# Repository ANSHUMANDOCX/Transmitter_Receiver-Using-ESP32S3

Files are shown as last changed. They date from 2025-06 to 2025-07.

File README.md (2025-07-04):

# Transmitter_Receiver-Using-ESP32S3
This is an RF ESP32-S3-based 10-channel Transmitter and Receiver which can also be used with the ESP-NOW protocol.

## PARTS
- ESP32-S3 WROOM-1U
- NRF24L01+ Transceiver Module
- SSD1309 2.42 inch OLED
- 2 Joysticks
- 4 Switches
- 2 Potentiometers

## PLAN
This is an RF transmitter with 10 channels, all of which support PWM output. The 10 channels include: 4 from joysticks 2 from potentiometers 4 from toggle switches

The setup includes a 2.42-inch OLED display to show the status of each channel, bind status, and battery level.

The receiver and transmitter will be programmed using an FTDI module.

The transmitter is designed to run for 5–6 hours on a 1000mAh LiPo battery (ideally).

The code is subject to change depending on in hand testing currently its just a sample code for controlling 10 servo motor with the 10 inputs.
# Transmitter 




# Receiver




## BOM

| Supplier | Item | Price (USD) |
|---|---|---|
| **LCSC** | Joystick (x2) | $0.85 |
| | SSD1309 2.42" OLED | $11.28 |
| | ESP32-S3 WROOM | $7.69 |
| | Potentiometer (x2) | $3.31 |
| | Switches (x4) | $2.33 |
| | MIC5219 3.3V LDO | $1.41 |
| | Pin headers+passive component | $7.71 |
| | Shipping | $3.74 |
| | **Total (LCSC)** | **$38.05**  |
| **JLCPCB** | PCB | $6.00 |
| | Shipping | $14.00 |
| | **Total (JLCPCB)** | **$20.00**  |
| **Sharvi Electronics** | nRF24L01+ + Heatset Insert + Charging Module+antenna | $9.53|
| | **Total (Sharvi)** | **$9.53** |
| **Electronics Comp.** | Battery | $5.38 |
| | **Total (Electronics Comp.)** | **$5.38** |

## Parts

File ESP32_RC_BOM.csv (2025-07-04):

Component | Price (USD) | Quantity | Total (USD) | BUY LINKS/LCSC PartNo.
ESP32-S3-WROOM-1U-N8 | 3.84 | 2 | 7.68 | C2980297
nRF24L01+ PA/LNA module | 2 | 2 | 4 | https://sharvielectronics.com/product/nrf24l01-sma-wireless-transceiver/
MIC5219-3.3YM5 Regulator | 0.28 | 5 | 1.4 | C5370977
Joysticks (XY axes) | 0.41 | 2 | 0.82 | C37323739,C37323741
Potentiometers | 1.65 | 2 | 3.3 | C2687317
Toggle Switches | 0.58 | 4 | 2.32 | C1788492
OLED Display (SSD1309) | 11.74 | 1 | 11.74 | C7466000
LiPo Battery (2000mAh) | 5.9 | 1 | 5.9 | https://www.electronicscomp.com/3.7v-2000mah-lipo-battery-india
passive components(resistor pinheaders etc) | 7 | 1 | 7 | C2881685,C2935876,C513768,C412252,C7419947,C2935874,C41366842,C2881435,C46635842,C3013349
Heat set inserts and antenna connector For case | 3.847 | 1 | 3.847 | https://sharvielectronics.com/product/pigtail-antenna-cable-rg1-13-ipex-3-0-female-to-ipex-3-0-female-connector-15cm-length/, https://sharvielectronics.com/product/rpsma-male-connector-to-ufl-ipex-interface-cable-15cm/, https://sharvielectronics.com/product/m2x3-mm-brass-heat-set-threaded-round-insert-nut/ https://sharvielectronics.com/product/ufl-male-to-sma-female-pcb-breakout-board/
PCB | 4 | 1 | 4
shipping |  |  | 18
 |  |  | 70.007

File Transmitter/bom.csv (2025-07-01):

Designator | Footprint | Quantity | Value | LCSC Part #
C1, C2, C6, C7, C9 | 805 | 5 | 0.1uF
C10, C11, C12, C13, C3, C4, C5 | 805 | 7 | 22uf
C8 | 1206 | 1 | 0.1uF
D1, D2 | 805 | 2 | Transmission Good
D3, D4 | 805 | 2 | LED
R1, R2 | 805 | 2 | 330R
R3, R4, R6, R7 | 805 | 4 | 10k
R5 | 805 | 1 | 2K
R8 | 1206 | 1 | 2K
SW1, SW3, SW2, SW4 | SW_Push_SPST_NO_Alps_SKRK | 2 | RESET
U1 | ESP32-WROOM-32E | 2 | ESP32-WROOM-32UE
U2, U4 | SOT-223-3_TabPin2 | 2 | AMS1117-3.3
U5 | SOT-223-3_TabPin2 | 1 | AMS1117-5.0

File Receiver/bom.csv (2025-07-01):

Designator | Footprint | Quantity | Value | LCSC Part #
C1 | 0603 | 1 | 1uF
C10, C11, C12, C13, C2, C3, C4, C6, C7, C8, C9 | 0603 | 11 | 0.1uF
C5 | 0603 | 1 | 22uF
D1, D2 | 0603 | 2 | LED
J1, J2, J3 | PinHeader_1x10_P2.54mm_Vertical | 3 | Conn_01x10_Pin
J10 | PinHeader_1x02_P1.27mm_Vertical | 1 | BAT
J11 | PinHeader_1x06_P1.27mm_Vertical | 1 | Conn_01x06_Pin
R1, R2, R7 | 0603 | 3 | 10K
SW2, SW3 | SW_Push_SPST_NO_Alps_SKRK | 2 | SW_Push
U1 | XCVR_ESP32-S3-WROOM-1U | 1 | ESP32-S3-WROOM-1U
U2, U4 | SOT-23-5 | 2 | MIC5219-3.3YM5
U3 | nRF24L01_Breakout | 1 | NRF24L01_Breakout

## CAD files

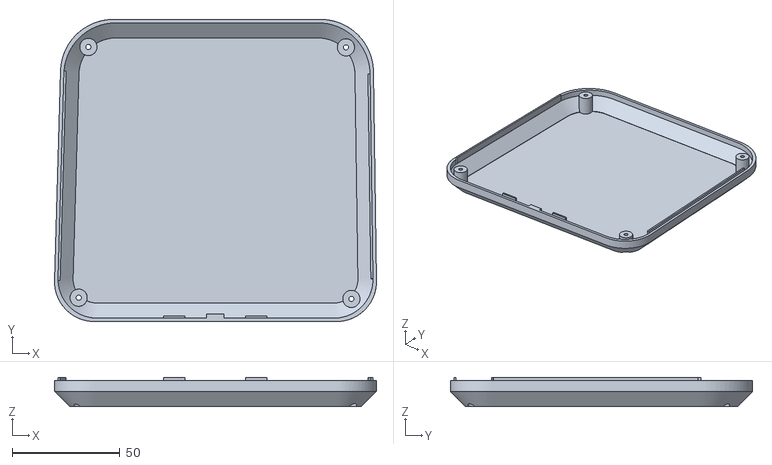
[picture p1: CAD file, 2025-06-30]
CAD/Bottom plate v2.stl
149.2 x 140.0 x 13.5

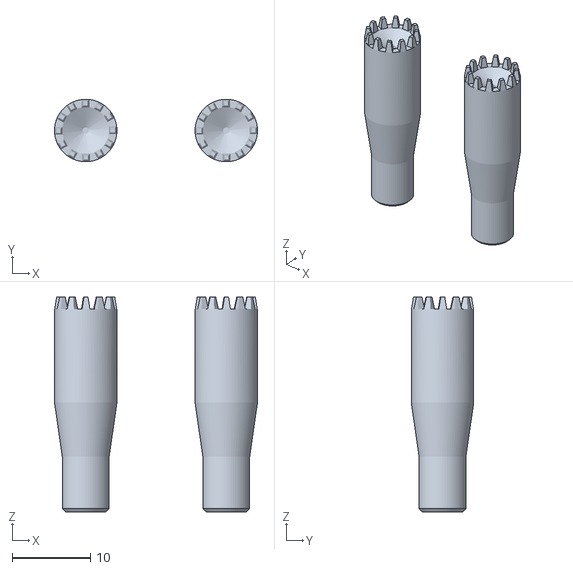
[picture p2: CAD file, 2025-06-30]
CAD/Sticks v3.stl
26.0 x 8.00 x 27.5

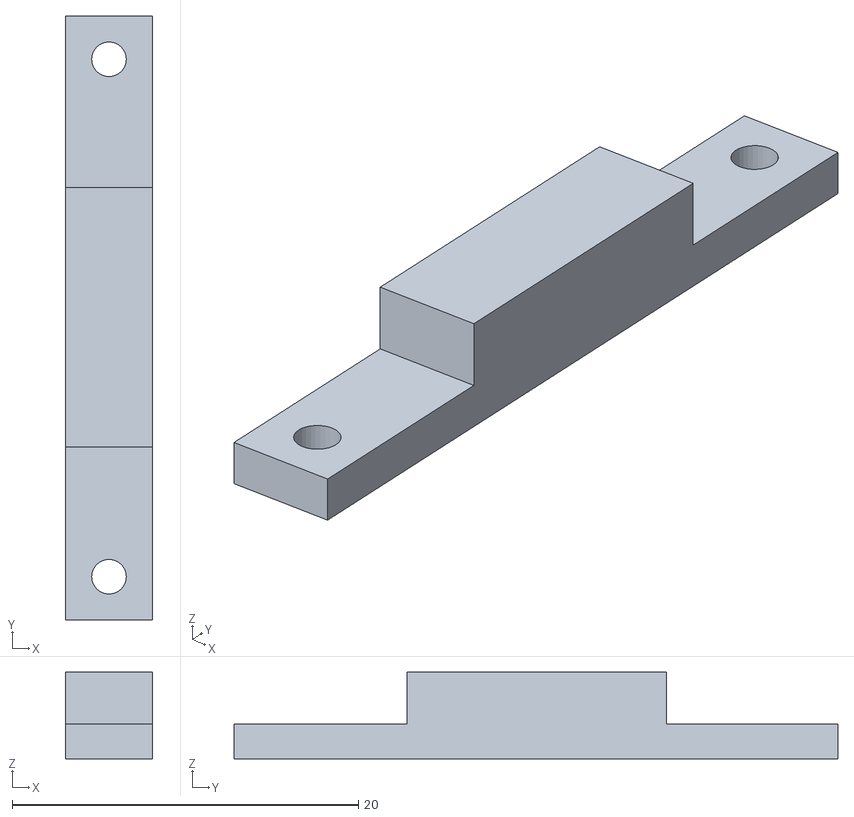
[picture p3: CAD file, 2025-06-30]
CAD/Joystick Placer v1.stl
5.00 x 34.9 x 5.00

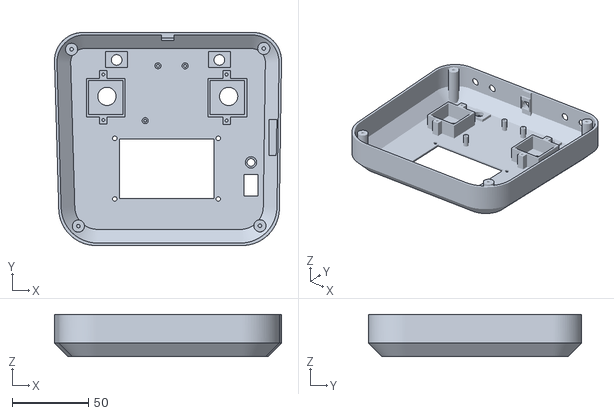
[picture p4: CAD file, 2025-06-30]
CAD/FRONT.stl
149.2 x 140.0 x 27.9

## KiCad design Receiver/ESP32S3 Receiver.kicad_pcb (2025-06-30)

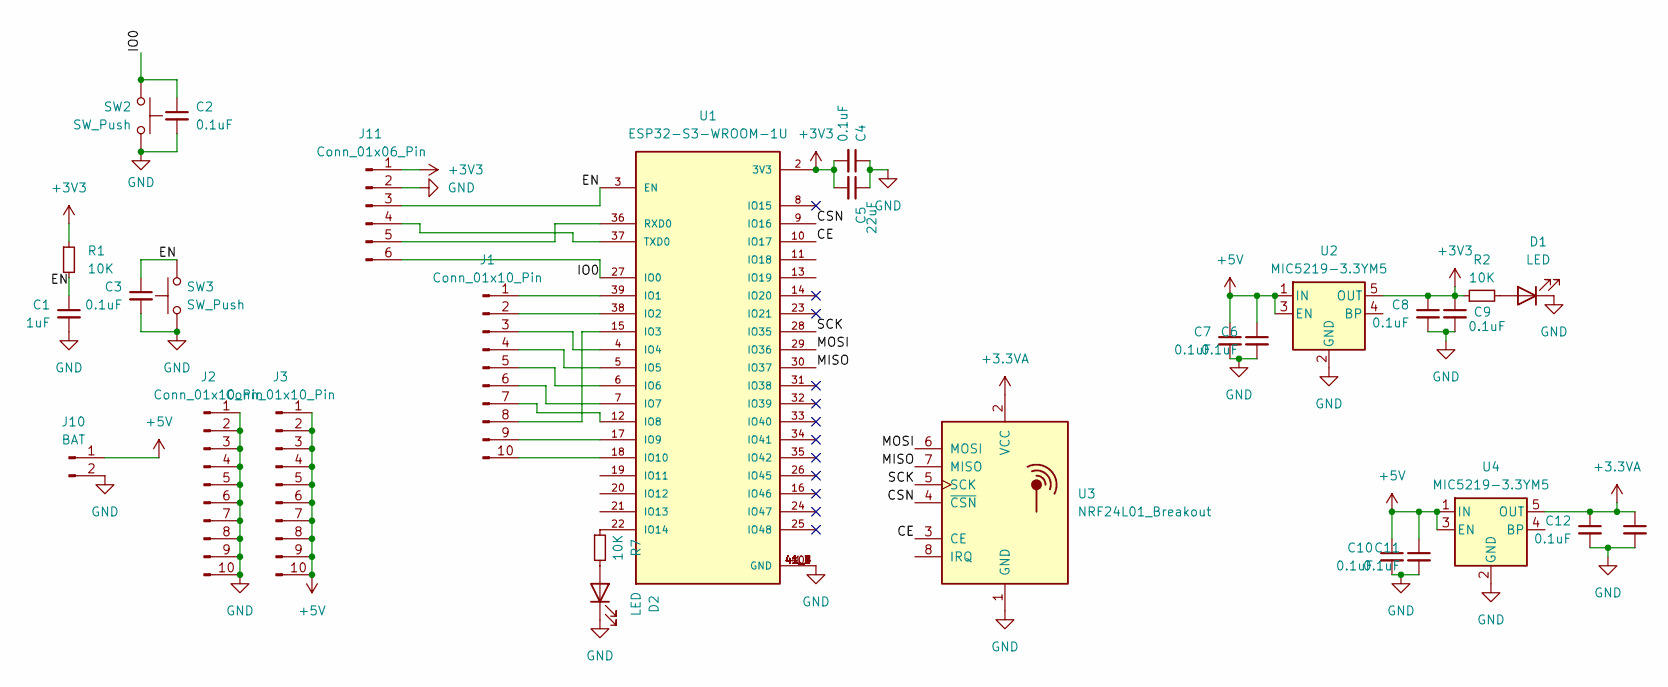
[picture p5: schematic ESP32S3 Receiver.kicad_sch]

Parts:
C1: 1uF; C_0603_1608Metric
C2, C3, C4, C6, C7, C8, C9, C10, C11, C12, C13: 0.1uF; C_0603_1608Metric
C5: 22uF; C_0603_1608Metric
D1, D2: LED; LED_0603_1608Metric_Pad1.05x0.95mm_HandSolder
J1, J2, J3: Conn_01x10_Pin; PinHeader_1x10_P2.54mm_Vertical
J10: BAT; PinHeader_1x02_P1.27mm_Vertical
J11: Conn_01x06_Pin; PinHeader_1x06_P1.27mm_Vertical
R1, R2, R7: 10K; R_0603_1608Metric
SW2, SW3: SW_Push; SW_Push_SPST_NO_Alps_SKRK
U1: ESP32-S3-WROOM-1U; XCVR_ESP32-S3-WROOM-1U; PARTREV v0.6
U2, U4: MIC5219-3.3YM5; SOT-23-5
U3: NRF24L01_Breakout; nRF24L01_Breakout

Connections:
+3.3VA: C12.1, C13.1, U3.2 (VCC), U4.5 (OUT)
+3V3: C4.2, C5.2, C8.1, C9.1, J11.1, R1.1, R2.1, U1.2 (3V3), U2.5 (OUT)
+5V: C6.1, C7.1, C10.1, C11.1, J3.1, J3.2, J3.3, J3.4, J3.5, J3.6, J3.7, J3.8, J3.9, J3.10, J10.1, U2.1 (IN), U2.3 (EN), U4.1 (IN), U4.3 (EN)
/CE: U1.10 (IO17), U3.3 (CE)
/CSN: U1.9 (IO16), U3.4 (~CSN)
/EN: C1.1, C3.1, J11.3, R1.2, SW3.2, U1.3 (EN)
/IO0: C2.1, J11.6, SW2.2, U1.27 (IO0)
/MISO: U1.30 (IO37), U3.7 (MISO)
/MOSI: U1.29 (IO36), U3.6 (MOSI)
/SCK: U1.28 (IO35), U3.5 (SCK)
GND: C1.2, C2.2, C3.2, C4.1, C5.1, C6.2, C7.2, C8.2, C9.2, C10.2, C11.2, C12.2, C13.2, D1.1 (K), D2.1 (K), J2.1, J2.2, J2.3, J2.4, J2.5, J2.6, J2.7, J2.8, J2.9, J2.10, J10.2, J11.2, SW2.1, SW3.1, U1.1 (GND), U1.40 (GND), U1.41_1 (GND), U1.41_2 (GND), U1.41_3 (GND), U1.41_4 (GND), U1.41_5 (GND), U1.41_6 (GND), U1.41_7 (GND), U1.41_8 (GND), U1.41_9 (GND), U2.2 (GND), U3.1 (GND), U4.2 (GND)
unnamed: D1.2 (A), R2.2
unnamed: D2.2 (A), R7.2
unnamed: J1.1, U1.39 (IO1)
unnamed: J1.2, U1.38 (IO2)
unnamed: J1.3, U1.4 (IO4)
unnamed: J1.4, U1.5 (IO5)
unnamed: J1.5, U1.6 (IO6)
unnamed: J1.6, U1.7 (IO7)
unnamed: J1.7, U1.12 (IO8)
unnamed: J1.8, U1.15 (IO3)
unnamed: J1.9, U1.17 (IO9)
unnamed: J1.10, U1.18 (IO10)
unnamed: J11.4, U1.37 (TXD0)
unnamed: J11.5, U1.36 (RXD0)
unnamed: R7.1, U1.22 (IO14)

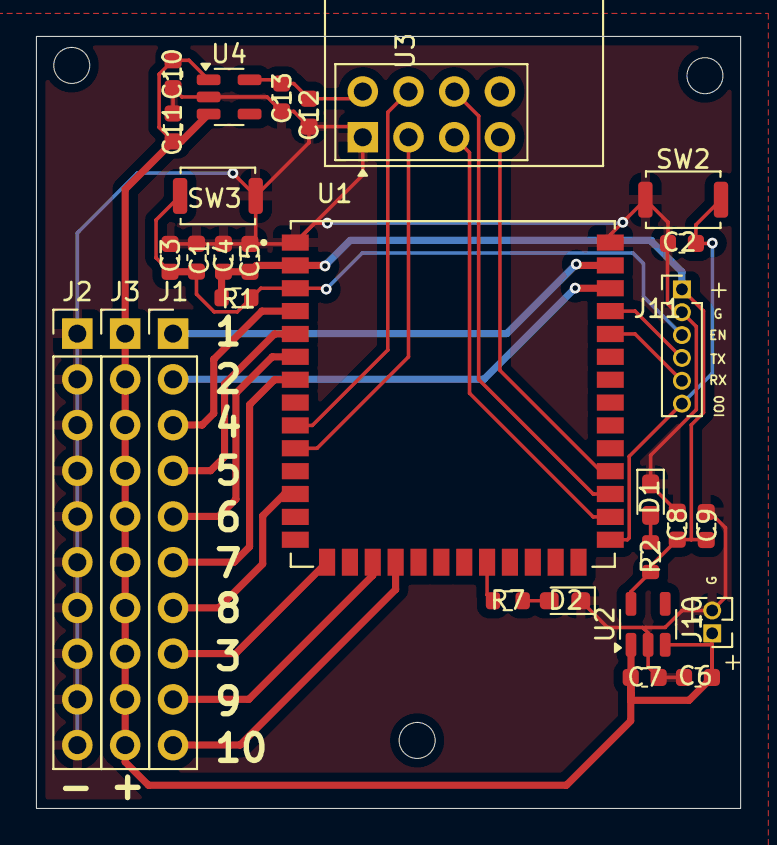
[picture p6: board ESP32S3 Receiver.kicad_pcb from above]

Board: 2 copper layers, 39.1 x 42.9 mm, 29 parts (0 on the bottom side), 26 nets.

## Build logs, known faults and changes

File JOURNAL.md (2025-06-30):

# ESP32S3 Transmitter and Receiver
- **Title:** ESP32S3 Transmitter and Receiver
- **Author:** Anshuman Tripathy
- **Description:** Transmitter and Receiver with 10 channel and a OLED Display.
- **Created_at:** 2025-06-10
- Total Time spent- 22hr

## **DAY 1- 17th June 2025: Started out with the Project**

Reasearched and planned out on what features the transmitter will have searched for the componets read the Datasheets. Since its my first time using esp32 s3 so i had to read the datasheet and look at example circuits properly. So, finally will be using these
- ESP32 S3 Wroom 1u
- SSD1309 2.42 inch oled
- 2 joysticks 2 potentiometes and 4 switched.
- nrf24l01 for rf communication.

Also, started out with the scheamtic 



time spent- 5 hr

## **Day 2 - 22nd June 2025: PCB**

Assigned, arranged th components on the PCB and also complted the routing. Its still a wip would need to complete a few things before finally completing it.



time spent- 4hr 

## **Day 3 - 24th June 2025 : PCB AND CAD**

Completed the PCB and started and complted a major chunk of the front portion of the transmitter where all the joysticks switches and Joysticks will be connected to.
The majority of the time was spent making the CAD. However its still not completed since i still need to make a place to hold the PCB in place.





Time Spent 6hr

## **Day 4 - 28th June 2025: Backplate and Sticks**

made the backplate for the case and the sticks for the joysticks.





time spent- 4 hr

## **Day 5- 29th June 2025 - RECEIVER**

Started and completed the receiver p simple circuit still was very happy to see no errors 




time spent- 2hr

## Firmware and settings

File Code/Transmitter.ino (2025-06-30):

#include <SPI.h>
#include <nRF24L01.h>
#include <RF24.h>
#include <Wire.h>
#include <Adafruit_GFX.h>
#include <Adafruit_SSD1306.h>

#define CE_PIN  11
#define CSN_PIN 12

#define SDA_PIN 20
#define SCL_PIN 19

RF24 radio(CE_PIN, CSN_PIN);
const byte address[6] = "00001";

int joy1X = 34, joy1Y = 35;
int joy2X = 36, joy2Y = 37;
int pot1  = 38, pot2  = 39;
int sw1   = 40, sw2   = 41, sw3 = 42, sw4 = 43;

struct DataPacket {
  uint16_t channels[10];
};

DataPacket data;

#define SCREEN_WIDTH 128
#define SCREEN_HEIGHT 64
Adafruit_SSD1306 display(SCREEN_WIDTH, SCREEN_HEIGHT, &Wire, -1);

void setup() {
  Serial.begin(115200);

  Wire.begin(SDA_PIN, SCL_PIN);
  display.begin(SSD1306_SWITCHCAPVCC, 0x3C);
  display.clearDisplay();
  display.setTextColor(SSD1306_WHITE);
  display.setTextSize(1);

  SPI.begin(35, 37, 36); // SCK, MISO, MOSI
  radio.begin();
  radio.setPALevel(RF24_PA_LOW);
  radio.setChannel(108);
  radio.setDataRate(RF24_250KBPS);
  radio.openWritingPipe(address);
  radio.stopListening();
}

void loop() {
  data.channels[0] = analogRead(joy1X);
  data.channels[1] = analogRead(joy1Y);
  data.channels[2] = analogRead(joy2X);
  data.channels[3] = analogRead(joy2Y);
  data.channels[4] = analogRead(pot1);
  data.channels[5] = analogRead(pot2);
  data.channels[6] = digitalRead(sw1) * 4095;
  data.channels[7] = digitalRead(sw2) * 4095;
  data.channels[8] = digitalRead(sw3) * 4095;
  data.channels[9] = digitalRead(sw4) * 4095;

  radio.write(&data, sizeof(data));

  display.clearDisplay();
  display.setCursor(0, 0);
  display.println("TX Channel Data:");
  for (int i = 0; i < 10; i++) {
    display.print("CH");
    display.print(i + 1);
    display.print(": ");
    display.println(data.channels[i]);
  }
  display.display();

  delay(50);
}

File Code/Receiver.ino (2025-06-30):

#include <SPI.h>
#include <nRF24L01.h>
#include <RF24.h>
#include <Servo.h>

#define CE_PIN  17
#define CSN_PIN 16

RF24 radio(CE_PIN, CSN_PIN);
const byte address[6] = "00001";

struct DataPacket {
  uint16_t channels[10];
};

DataPacket data;

Servo servos[10];
int servoPins[10] = {1, 2, 3, 4, 5, 6, 7, 8, 9, 10};

void setup() {
  Serial.begin(115200);

  for (int i = 0; i < 10; i++) {
    servos[i].attach(servoPins[i]);
  }

  SPI.begin(35, 37, 36); // SCK, MISO, MOSI
  radio.begin();
  radio.setPALevel(RF24_PA_LOW);
  radio.setChannel(108);
  radio.setDataRate(RF24_250KBPS);
  radio.openReadingPipe(0, address);
  radio.startListening();
}

void loop() {
  if (radio.available()) {
    radio.read(&data, sizeof(data));

    for (int i = 0; i < 10; i++) {
      int angle = map(data.channels[i], 0, 4095, 0, 180);
      servos[i].write(angle);
    }
  }
}
